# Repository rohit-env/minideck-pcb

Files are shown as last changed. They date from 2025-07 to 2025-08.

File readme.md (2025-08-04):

# Rohit's minideck PCB

so I went off and designed a whole cyberdeck pcb, it’s kinda sick, it's a full-on deck with ports, buttons, blinky stuff, and that clean hacker aesthetic. built it because laptops are boring and carrying around raw PCBs just hits different.the board’s got space for a pi, a couple usb ports, an oled, and some clicky switches. stuff’s laid out in a way that makes sense, but also makes you look like you’re about to jack into the matrix at a coffee shop. the idea is simple cram as much functional coolness as possible onto one board and still make it portable enough to flex at meetups. this whole thing started with a sketch on a sticky note and now it’s a real life project(obviously i need money to make it real). i even left space for expansion headers because future proofing or whatever. no idea how many late nights went into routing this lol



---

# features 

Uses Raspberry-pi CM4 form-factor for main SBC.

5inch or 4.3inch LCD display with support for another External Display out port.

Uses ESP32-S2 for all the secondary functions including keyboard and mouse control.

61 key customizable keyboard, 6 shoulder button for navigation.

3D hall-effect joystick is used for proper Mouse control.

10000mAh(21700) 2S battery can be used for main power source.

USB-PD 2Amps fast charging using USB-C port.

One USB-A and display out for external display.

USB-C formfactor Nurolink/docking port with UART, I2C.

---

| Image | Description |
|---|---|
|  | top |

| Image | Description |
|---|---|
|  | side |

| Image | Description |
|---|---|
|  | top side |

| Image | Description |
|---|---|
|  | main pcb render |

| Image | Description |
|---|---|
|  | display pcb render |

| Image | Description |
|---|---|
|  | main pcb |

| Image | Description |
|---|---|
|   | display pcb |

----

# BOM

| **Component** | **Description** | **Qty** | **Estimated Price (USD)** | **Link** |
|---|---|---|---|---|
| **PCB** | Custom PCB | 1 | $92 (without pcba after $20 coupon) | JLCPCB  |
| **4.3 inch display** | Display for the deck | 1 | $36.16 | [Robocraze](https://robocraze.com/products/waveshare-4-3inch-dsi-lcd-capacitive-touch-display-800-480-for-raspberry-pi) |
| **21700 batteries** | Batteries | 1 (pair) | $10.41 | [Drkstore](https://www.drkstore.in/molicel-inr-21700-p45b-3-6v-4500mah-10c-li-ion-battery/) |
| **5V Voltage Regulator** | Power regulator for the display | 2 | $11.76 | [Robocraze](https://robocraze.com/products/dfrobot-multi-output-dc-dc-buck-converter-module-3-3v-5v-9v-12v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) |
| **ESP32 Microcontroller**| Controls everything in the device (keyboard, mouse, etc.) | 1 | $0 | Already available |
| **Raspberry Pi Compute Module** | Heart of the device | 1 | $80 | [Robu](https://robu.in/product/raspberry-pi-compute-module-5-2gb-32gb/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) |

BOM: $229

# gallery






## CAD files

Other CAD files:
CAD/fusionparts/body_bottom.f3d
CAD/fusionparts/body_top.f3d
CAD/fusionparts/display_bottom.f3d
CAD/fusionparts/display_top.f3d
CAD/fusionparts/mid_frame.f3d

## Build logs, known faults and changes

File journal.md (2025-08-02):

total hours spent: 43 hours.

### July 8, 2025  
**time spent:** 2 hours  

got started with the power stuff today because that felt like a good anchor  
opened up a blank KiCad sheet and just kinda sat there before committing to the first buck converter  
threw in a couple AP62300s, added some random caps that looked about right  
did basic power rails like +3.3VA and +5V, mostly by guessing current draw  
honestly spent more time figuring out resistor values than placing parts  
it's still super rough, but at least the board’s not completely empty anymore  
definitely not thinking about routing yet

| what happened | image |
|---|---|
| got the power rails and buck converters roughly figured out |   |

---

### July 9, 2025  
**time spent:** 1.5 hours  

dove headfirst into HDMI today and instantly regretted it  
the connector footprint was cursed and I had to double-check every diff pair  
wired up the HDMI chip and some tiny filter caps for signal integrity  
had to decide whether to bother with hotplug detection and i just YOLO’d it in  
tried to keep traces as short as possible even though I haven’t routed anything  
also added pull-ups and random ESD protection that I may or may not actually populate  
got through it alive, but just barely

| what happened | image |
|---|---|
| threw in the hdmi stuff, wasn’t sure if i was wiring it right tbh |  |

---

### July 11, 2025  
**time spent:** 2.5 hours  

today was CM4 Lite day, and man this thing has a crazy number of pins  
literally had to scroll through three different PDFs to not mess up the IO mapping  
figured out where to connect PCIe and eMMC signals even though I’m not using either  
started drawing out the main headers and labeling them so I wouldn’t cry later  
threw in level shifters and testpoints just to be safe  

| what happened | image |
|---|---|
| added the cm4 lite footprint and some essentials around it |  |

---

### July 12, 2025  
**time spent:** 1 hour  

today was about the esp32 and the USB hub, two chips I really like but hate wiring  
added the esp32 footprint and spent too long assigning IOs  
for the usb hub, I was constantly bouncing between the datasheet and KiCad  
wired up USB upstream/downstream lines and crossed my fingers on signal integrity  
threw in some debug headers and left room for ESD stuff I haven’t decided on yet  
also started routing logic enable signals to give me more control later  
kinda messy but functionally complete

| what happened | image |
|---|---|
| hooked up the esp and usb hub chip, still unsure about esd protection here | |

---

### July 14, 2025  
**time spent:** 1.5 hours  

this was cleanup day, had to declutter a lot of overlapping nets  
focused on GPIO and voltage domains because things were starting to get scary  
double checked voltage levels everywhere and pulled back any accidental 5V hits  
renamed nets to stuff like USB_D+ and PWR_BTN so I don’t get lost later  
added a few jumpers where I needed config flexibility

| what happened | image |
|---|---|
| the gpio, ethernet, sd signals etc., are getting crowded |
  |

---

### July 16, 2025  
**time spent:** 2 hours  

felt like expanding the UI side today, so buttons and switches got added  
dropped in an IO expander to control all the random toggles I want  
added RGB LED, backlight control, and the mandatory cyberpunk toggle  
also threw in debug pads and labeled everything just in case I forget stuff later  
double checked how the esp talks to the neopixel

| what happened | image |
|---|---|
| added a bunch of buttons, switches, and gpio expands |  |

---

### July 18, 2025  
**time spent:** 1 hour  

focused entirely on the battery and power switch logic today  
added charging ICs, battery monitor, and some MOSFET magic for switching  
realized I forgot to add thermistor protection, so threw that in last minute  
checked current sense resistor values like 5 times because battery fires aren’t cool  
rewired the main power path so everything’s a bit safer  
design is power-heavy now but kinda elegant  
will probably still debug it with a fire extinguisher nearby

| what happened | image |
|---|---|
| threw in the power switch logic and battery protection circuit |
  |

---

### July 20, 2025  
**time spent:** 3 hours  

long session today, mostly organizing the whole schematic properly  
split things into hierarchy sheets because the top level was getting out of control  
reassigned power domains and labeled them to make layout cleaner later  
caught a bunch of dumb mistakes like misnamed nets and flipped diodes  
also started writing notes inside schematic blocks to help future-me  
deleted some sketchy looking wires and redrew for clarity  
design now feels like an actual engineering thing and not a spaghetti nightmare

| what happened | image |
|---|---|
| general cleanup and better power domain separation | 
  |

---

### July 21, 2025  
**time spent:** 2 hours  

this one was about the screen and making sure it won’t fry  
hooked up the LCD interface and added ESD resistors on all the touch lines  
tried to keep traces short even though I’m still in schematic mode  
double checked the display’s backlight, touchscreen, and data lines  
added a debug header just to probe signals later if things don’t work  
organized the connector pins to make layout easier  
this part was clean.

| what happened | image |
|---|---|
| display interface is finally somewhat sane |
   |

---

### July 22, 2025  
**time spent:** 1.5 hours  

wrapped up the final round of cleanup and review today  
triple-checked pinouts, footprints, and power rails for errors  
added fiducials, test points, and random extras like boot jumpers  
also finalized the USB-C and HDMI protection stuff  

---

### July 23, 2025
**time spent:** 4 hours  

worked on deciding the dimensions for the pcb borders and made sure that it fit my case dimensions that i have planned, also many components i placed on the board, just the process of deciding the border length took a lot of time, started routing the pcb and i finished abtu 20% of it, i am thinking of importing it to easy eda pro and autorouting it but i want the source files so ill keep it

---

### july 24,2025 
**time spent:** 3 hours  

today i finished routing the display pcb, and started routing the main pcb, it did take a lot of retries since i had to replace parts and i finally found a suitable arrangement, routig all the parts in the main pcb was pretty hectic, ive finished like 70% of it, i've got school stuff to do now so imma take the night off

---

### July 26, 2025
**time spent:** 2 hours 

started work on the display PCB today and honestly this one's way calmer than the main board  
got the basic stuff in first power input, the FPC connector for the screen, and some random passives  
had to rotate the layout like 3 times to make the FPC orientation make sense  
added pull-up resistors.

| what happened | image |
|---|---|
| finished the display PCB design, it’s looking clean and minimal |  |

---

### July 28, 2025  
**time spent:** 3 hours  

big day finished up the main PCB layout and it’s giving boss battle energy  
revisited every sheet and double checked for footprint mismatches or missing caps  
replaced some jank passives from earlier with proper parts and cleaned up nets  
went full sent on layout had to rip up the power plane.

| what happened | image |
|---|---|
| final layout of the main PCB, all the chaos finally connected |  |

---

### july 29,2025
**time spent:** 3 hours  

finished doing the firmware, got nothing to say about this one.

---

### July 29, 2025 ( in the night ) 
**time spent:** 2 hours  
Did more work on the case for the display PCB today. Most of the time went into figuring out the outer dimensions so the board actually fits in clean. Kept adjusting a few mm here and there to match the rough size I had in my head. Took way longer than it should’ve. Once that was sorted, I started adding the cutouts and screw holes. made sure the ports had breathing room, and triple-checked all the hole spacing. Don’t wanna be that guy who forgets to leave space for the USB port. Didn’t bother adding fillets or rounded corners yet just getting the basic shape right for now. Might tweak the aesthetics later once I test fit the first cut. But yeah, it’s finally starting to look like a proper case.
| what happened | image |
|---|---|
| sneak peaks |  |
| sneak peaks |  |

---

### July 30, 2025( early morning )
**time spent** 4 hours
Started designing the bottom half of the display case today. The goal was to keep it simple but still make sure everything lines up clean. Took a bit of time messing with dimensions—mainly double checking hole positions it matched the PCB layout. Rounded off the corners to make it less boxy and added a small notch for cable clearance later if I need it. The cutouts for the screen area and the mounts came out nice in the 3D preview.

Honestly just getting the case to sit right with the PCB was half the battle, but it looks solid now. Ready to move on to the top half next.
| what happened | image |
|---|---|
| sneak peaks |  |
| sneak peaks |  |

---

### July 30, 2025( night)
**time spent** 2 hours

I started working on the top half of the case. This part was kind of annoying, to be honest. I had to figure out the exact cutout for the display and ensure it sat flush without pressing too hard on the screen. It took a few tries to get the depth right. I kept toggling between the model and the actual display dimensions just to be sure.Then came the USB port clearance, which was a real hassle. Tiny shifts made it either not fit or too loose. I finally added a small beveled area around it so it wouldn’t scrape while plugging things in. I also had to make sure the mounting holes lined up perfectly with the bottom half. I used offsets and several measuring tools in Fusion to get it right. I added a little lip around the edges to help with alignment when snapping it on, and I created some space inside for routing wires from the display. It’s not the prettiest lid, but it gets the job done. I might refine the outer surface later to make it look cleaner. For now, I’m just focused on function.
| what happened | image |
|---|---|
| sneak peaks |  |
| sneak peaks |  |

---

### July 31,2025
**time spent** 2 hours

spent most of the evening just modeling the top half of the display case. it honestly took longer than expected lining everything up with the pcb was kind of a pain. had to double check the display cutout, standoff placement, and make sure nothing would crash into the components later. i played around with the screen window quite a bit… didn’t want it to look bulky, but also didn’t want it too snug and risk it scraping the screen when assembled. added a few guiding walls inside so the pcb can sort of “slot in” when it’s time. should help with alignment too. tweaked tolerances here and there, especially around the screen opening. might still need adjustments after the first print, but visually it’s looking nice.
not the most fun part of the build, but we’re getting there.

| what happened | image |
|---|---|
| sneak peaks | 
 |
| sneak peaks |   |

---

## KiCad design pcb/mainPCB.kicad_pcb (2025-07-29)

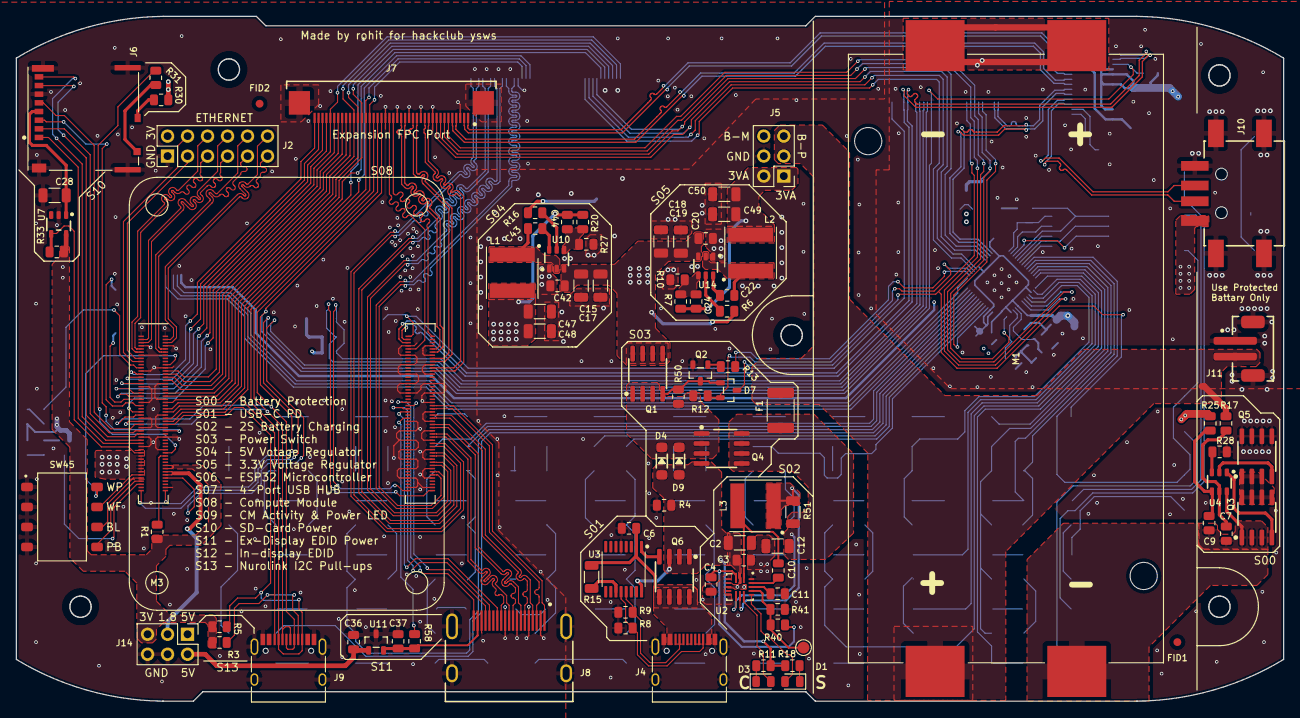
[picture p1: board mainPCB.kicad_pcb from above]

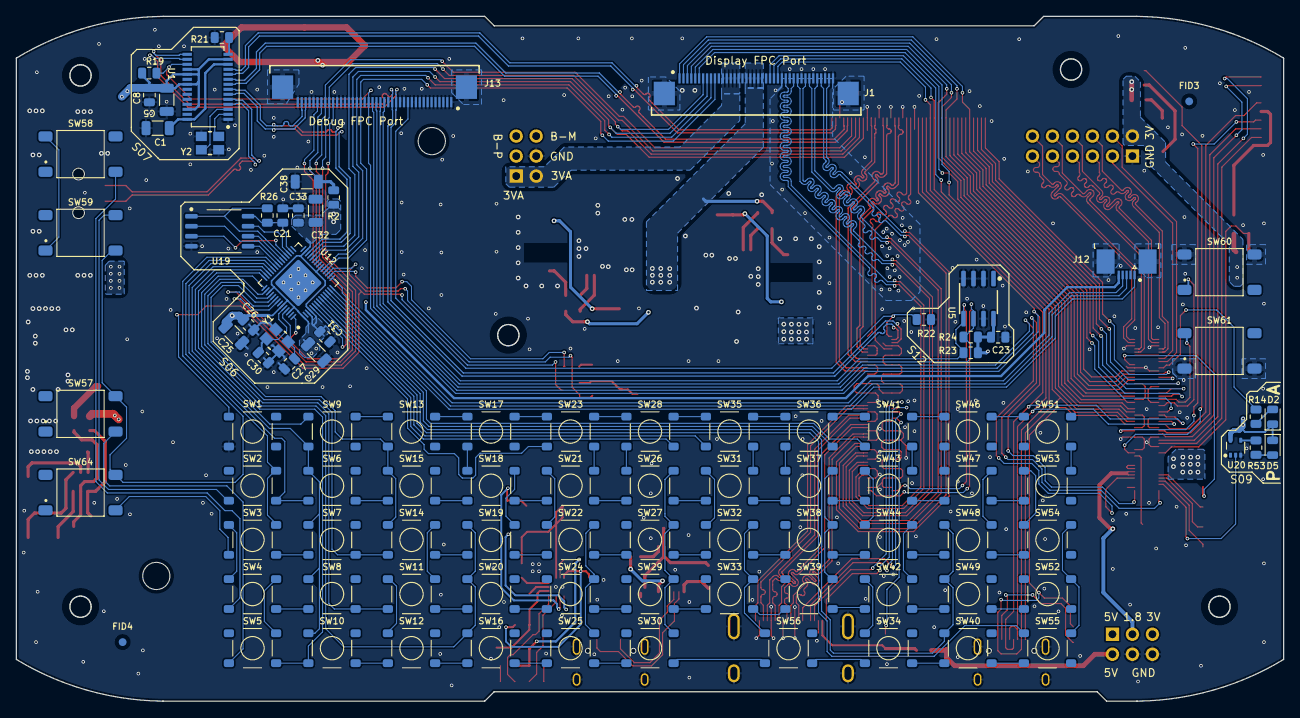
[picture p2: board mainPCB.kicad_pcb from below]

Board: 4 copper layers, 161.0 x 87.0 mm, 194 parts (97 on the bottom side), 260 nets.

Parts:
C1, C5, C15, C17, C18, C19, C25, C28, C29, C32, C38: 10uF; Capacitor-1206
C2, C12, C47, C48, C49, C50: 22uF; Capacitor-1206
C3, C4, C6, C11: 1uF; Capacitor-0805
C7, C8, C9, C10, C20, C21, C22, C23, C26, C31, C33, C36, C37, C42, C43: 0.1uF; Capacitor-0805
C24, C44: 100pF; Capacitor-0805
C27, C30: 16pF; Capacitor-0805
D1, D2, D3, D5: LED; LED-0805
D4, D9: MBR0540T3G; Diode-SOD-123
D7: BAT54C-(SOT23); SOT-23-3
F1: 0ZCG0260BF2B; Fuse-1812
FID1, FID2, FID3, FID4: Fiducial; Fiducial_1mm_Mask2mm
H1, H2, H3, H4, H5: MountingHole_Pad; MountingHole-M2.5-D2.7mm
J1, J7, J13: CF20401D0R0-NH; FPC-40-0.5mm-horizontal
J2: Conn_02x06-(RS2-12-G); PinHeader_2x06_P2.54mm_Vertical
J4, J9: 12402012E212A; USB_C-Female-(16-Pin)
J5, J14: Conn_02x03-(RS2-06-G); PinHeader_2x03_P2.54mm_Vertical
J6: Micro_SD_Card_Det; SD-Micro-Push-Push(MOLEX_503398-1892)
J8: HDMI_A-(2086581051); HDMI(EDAC 690-019-298-412)
J10: 629104190121; USB_A-horizontal-SMD-3
J11: B2B-PH-SM4-TB; JST-PH2-Vertical
J12: SFV5R-2STBE1HLF; FPC-5-0.5mm-horizontal
L1, L2: 10uH-(74404064100); Inductor-6.0x6.0xH4.5
L3: 6.8uH-(74404064068); Inductor-6.0x6.0xH4.5
M1: keystone-PN1048; Battery_holder-18650x2(keystone-PN1048)
M3: DF40C-100DS-0.4V(51); Module-ComputeModule4-CM4
Q1, Q4: DMP3037LSS-13; SOP-8
Q2: BCW66HVL-(2N2222); SOT-23-3
Q3, Q5: MOSFET-N; SOP-8
Q6: AOSP36326C; SOP-8
R1, R22, R28: 2.2k; Resistor-0805
R2, R3, R4, R5, R10, R12, R27, R40, R41, R50, R58: 10k; Resistor-0805
R6, R16, R19, R23, R24, R26, R33: 100k; Resistor-0805
R7: 33.2K; Resistor-0805
R8, R9: 5.1k; Resistor-0805
R11, R14, R18, R53: 1k; Resistor-0805
R13, R30, R31: 220R; Resistor-0805
R15: 5.1k; Resistor-1206
R17, R25: 330R; Resistor-0805
R20: 56.2k; Resistor-0805
R21: 2.7k; Resistor-0805
R51: 50mR; Resistor-1206
SW1, SW2, SW3, SW4, SW5, SW6, SW7, SW8, SW9, SW10, SW11, SW12, SW13, SW14, SW15, SW16, SW17, SW18, SW19, SW20, SW21, SW22, SW23, SW24, SW25, SW26, SW27, SW28, SW29, SW30, SW31, SW32, SW33, SW34, SW35, SW36, SW37, SW38, SW39, SW40, SW41, SW42, SW43, SW44, SW46, SW47, SW48, SW49, SW51, SW52, SW53, SW54, SW55, SW56: PTS526 SK15 SMTR2 LFS-(C&K); Switch-4x4x1.5-(PTS526)
SW45: Switch-6.2X4-DIP(DS04-254-2-04BK)
SW57, SW58, SW59, SW60, SW61, SW64: TS04-66-85-BK-160-SMT; Switch-6x6xXX-Extend
TP16: THERM; TestPoint-Pad_D1.5mm
U1: FE1.1S-BSOP28BCN; SSOP-28 (3.9x9.9x0.635)
U2: MP2615CGQ-Z-(QFN-16); QFN-16 (3x3-MP2615)
U3: IP2721-(TSSOP-16); TSSOP-16
U4: MM3220/S8252-(SOT-23-6); SOT-23-6
U5: AT24CM01-SSHM-B; SOP-8
U7: RT9742GGJ5; SOT-23-5
U10, U14: AP62300TWU-7-(SOT-23-6); SOT-23-6
U11: RT9742SNGV; SOT-23-3
U12: ESP32-S2FH4; QFN-56 (7x7x0.4)
U19: W25Q128JVS; SOIC-8-208mil
U20: 74LVC1G07SE-7-(SOT-353); SOT-353
Y1: 40mhz-(RH100-40.000-16-F-1010-TR); Crystal-3225-SMD
Y2: 12MHz-(RH100-12.000-12-1010-X-TR-NS2); Crystal-3225-SMD

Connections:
1: SW2.4, SW3.4, U12.38 (GPIO34)
1D+: J10.3 (D+), U1.5 (DP4)
1D-: J10.2 (D-), U1.4 (DM4)
2: SW6.3, SW7.3, SW8.3, SW9.1, SW10.3, U12.40 (GPIO36)
2D+: J13.39, U1.7 (DP3), U12.26 (GPIO20/USB_P)
2D-: J13.38, U1.6 (DM3), U12.25 (GPIO19/USB_N)
3: SW13.1, SW14.3, SW15.3, U12.47 (GPIO42)
3D+: J7.4, U1.9 (DP2)
3D-: J7.5, U1.8 (DM2)
4: SW16.3, SW19.3, SW20.3, U12.43 (GPIO39)
4D+: J7.1, U1.11 (DP1)
4D-: J7.2, U1.10 (DM1)
5: SW23.1, U12.6 (GPIO1)
6: SW28.2, U12.7 (GPIO2)
7: SW35.1, U12.8 (GPIO3)
8: SW36.2, U12.11 (GPIO6)
9: SW41.1, U12.12 (GPIO7)
10: SW40.3, SW48.3, SW49.3, U12.10 (GPIO5)
11: SW55.3, U12.9 (GPIO4)
12: SW57.4, SW59.2, SW64.4, U12.37 (GPIO33)
+3.3V: D2.A, D5.A, J2.2, J14.5, M3.84 (+3.3v_(Output)), M3.86 (+3.3v_(Output)), R1.1, R3.1, R5.1, R30.1, R33.1, U7.5 (IN), U20.5 (VCC)
+3.3VA: C5.1, C8.1, C24.2, C25.2, C26.2, C29.2, C31.2, C32.2, C33.2, C49.2, C50.2, J1.12, J1.13, J1.14, J1.15, J1.16, J5.1, J5.2, J12.5, L2.2, R2.2, R7.1, R19.2, U1.13 (VD33), U1.18 (VBUSM), U1.19 (BUSJ), U1.21 (VD33_O), U1.26 (OVCJ), U12.1 (VDDA), U12.3 (VDD3P3), U12.4 (VDD3P3), U12.20 (VDD3P3_RTC), U12.27 (VDD3P3_RTC_IO), U12.45 (VDD3P3_CPU), U12.51 (VDDA), U12.54 (VDDA)
+5V: C23.2, C36.1, C44.2, C47.2, C48.2, J10.1 (VBUS), J14.1, J14.2, L1.2, M3.77 (+5v_(Input)), M3.79 (+5v_(Input)), M3.81 (+5v_(Input)), M3.83 (+5v_(Input)), M3.85 (+5v_(Input)), M3.87 (+5v_(Input)), R20.1, R23.2, R24.2, U5.8 (VCC), U11.1 (IN)
+12V: C2.2, C3.2, D4.A, D9.A, Q4.4, Q6.1, Q6.2, Q6.3, R4.1, R11.2, R18.2, U2.2 (VIN), U3.16 (VBUS)
+BATT: F1.2, J5.3, J5.5, J11.2, M1.1, R17.1
+VDC: C12.2, F1.1, Q4.5, Q4.6, Q4.7, Q4.8, R51.1, U2.9 (BATT)
-BATT: C7.1, C9.1, M1.3, Q3.1, Q3.2, Q3.3, U4.6 (GND)
/+1.8v: J14.3, M3.88 (+1.8v_(Output)), M3.90 (+1.8v_(Output))
/ACOK: D1.C, U2.12 (*ACOK)
/Activity_LED: M3.21 (PI_nLED_Activity), R14.2
/BT_nDis: M3.91 (BT_nDisable), SW45.3B
/Charger_SW_Out: L3.1, R51.2, U2.10 (CSP)
/EEPROM_nWP: M3.20 (EEPROM_nWP), SW45.1B
/ETH_0_N: J2.9, M3.10 (Ethernet_Pair0_N)
/ETH_0_P: J2.10, M3.12 (Ethernet_Pair0_P)
/ETH_1_N: J2.11, M3.6 (Ethernet_Pair1_N)
/ETH_1_P: J2.12, M3.4 (Ethernet_Pair1_P)
/ETH_2_N: J2.5, M3.9 (Ethernet_Pair2_N)
/ETH_2_P: J2.6, M3.11 (Ethernet_Pair2_P)
/ETH_3_N: J2.7, M3.5 (Ethernet_Pair3_N)
/ETH_3_P: J2.8, M3.3 (Ethernet_Pair3_P)
/ETH_LEDG: J2.4, M3.17 (Ethernet_nLED2(3.3v))
/ETH_LEDY: J2.3, M3.15 (Ethernet_nLED3(3.3v))
/GLOBAL_EN: J13.21, M3.99 (Global_EN)
/GPIO2: J1.26, J7.26, J9.A5 (CC1), J9.B5 (CC2), M3.58 (GPIO2), R5.2
/GPIO3: J1.25, J7.27, J9.A8 (SBU1), J9.B8 (SBU2), M3.56 (GPIO3), R3.2
/GPIO4: J1.24, M3.54 (GPIO4)
/GPIO6: J7.31, M3.30 (GPIO6)
/GPIO7: J7.37, M3.37 (GPIO7)
/GPIO8: J1.1, J7.36, M3.39 (GPIO8)
/GPIO9: J1.3, J7.29, M3.40 (GPIO9)
/GPIO10: J1.4, J7.28, M3.44 (GPIO10)
/GPIO11: J1.2, J7.30, M3.38 (GPIO11)
/GPIO12: J7.38, M3.31 (GPIO12)
/GPIO13: J7.32, M3.28 (GPIO13)
/GPIO14: J7.25, J9.A7 (D-), J9.B7 (D-), M3.55 (GPIO14)
/GPIO15: J7.24, J9.A6 (D+), J9.B6 (D+), M3.51 (GPIO15)
/GPIO17: J1.5, M3.50 (GPIO17)
/GPIO18: J7.35, M3.49 (GPIO18)
/GPIO19: J7.33, M3.26 (GPIO19)
/GPIO20: J7.39, M3.27 (GPIO20)
/GPIO21: J7.40, M3.25 (GPIO21)
/GPIO24: M3.45 (GPIO24), SW60.1
/GPIO25: M3.41 (GPIO25), SW61.3
/GPIO26: J7.34, M3.24 (GPIO26)
/GPIO27: J1.6, M3.48 (GPIO27)
/GPIO_VREF: M3.78 (GPIO_VREF(1.8v/3.3v_Input)), R1.2
/HDMI0_CK_N: J1.28, M3.190 (HDMI0_CLK_N)
/HDMI0_CK_P: J1.30, M3.188 (HDMI0_CLK_P)
/HDMI0_D0_N: J1.31, M3.184 (HDMI0_TX0_N)
/HDMI0_D0_P: J1.33, M3.182 (HDMI0_TX0_P)
/HDMI0_D1_N: J1.34, M3.178 (HDMI0_TX1_N)
/HDMI0_D1_P: J1.36, M3.176 (HDMI0_TX1_P)
/HDMI0_D2_N: J1.37, M3.172 (HDMI0_TX2_N)
/HDMI0_D2_P: J1.39, M3.170 (HDMI0_TX2_P)
/HDMI0_HOTPLUG: M3.153 (HDMI0_HOTPLUG), R58.2
/HDMI0_SCL: J13.19, M3.200 (HDMI0_SCL), R24.1, U5.6 (SCL)
/HDMI0_SDA: J13.18, M3.199 (HDMI0_SDA), R23.1, U5.5 (SDA)
/HDMI1_CEC: J8.13 (CEC), M3.149 (HDMI1_CEC)
/HDMI1_CK_N: J8.12 (CK-), M3.166 (HDMI1_CLK_N)
/HDMI1_CK_P: J8.10 (CK+), M3.164 (HDMI1_CLK_P)
/HDMI1_D0_N: J8.9 (D0-), M3.160 (HDMI1_TX0_N)
/HDMI1_D0_P: J8.7 (D0+), M3.158 (HDMI1_TX0_P)
/HDMI1_D1_N: J8.6 (D1-), M3.154 (HDMI1_TX1_N)
/HDMI1_D1_P: J8.4 (D1+), M3.152 (HDMI1_TX1_P)
/HDMI1_D2_N: J8.3 (D2-), M3.148 (HDMI1_TX2_N)
/HDMI1_D2_P: J8.1 (D2+), M3.146 (HDMI1_TX2_P)
/HDMI1_HOTPLUG: J8.19 (HPD/HEAC-), M3.143 (HDMI1_HOTPLUG)
/HDMI1_SCL: J8.15 (SCL), M3.147 (HDMI1_SCL)
/HDMI1_SDA: J8.16 (SDA), M3.145 (HDMI1_SDA)
/HDMI_5v: C37.1, J8.18 (+5V), R58.1, U11.2 (OUT)
/PCIE_CLK_N: J7.17, M3.112 (PCIe_CLK_N)
/PCIE_CLK_P: J7.18, M3.110 (PCIe_CLK_P)
/PCIE_CLK_nREQ: J7.20, M3.102 (PCIe_CLK_nREQ)
/PCIE_RX_N: J7.14, M3.118 (PCIe_RX_N)
/PCIE_RX_P: J7.15, M3.116 (PCIe_RX_P)
/PCIE_TX_N: J7.11, M3.124 (PCIe_TX_N)
/PCIE_TX_P: J7.12, M3.122 (PCIe_TX_P)
/PCIE_nRST: J7.21, M3.109 (PCIe_nRST)
/PWR_LED: M3.95 (nPI_LED_PWR), U20.2
/RUN_PG: J13.20, M3.92 (RUN_PG)
/Reserved: M3.76 (Reserved), R31.1
/SD_CLK: J6.5 (CLK), M3.57 (SD_CLK)
/SD_CMD: J6.3 (CMD), M3.62 (SD_CMD)
/SD_DAT0: J6.7 (DAT0), M3.63 (SD_DAT0)
/SD_DAT1: J6.8 (DAT1), M3.67 (SD_DAT1)
/SD_DAT2: J6.1 (DAT2), M3.69 (SD_DAT2)
/SD_DAT3: J6.2 (DAT3/CD), M3.61 (SD_DAT3)
/SD_PWR: C28.2, J6.4 (VDD), U7.1 (OUT)
/SD_PWR_ON: M3.75 (SD_PWR_ON), R33.2, U7.4 (EN)
/USB2_N: J13.16, M3.103 (USB2_N), U1.15 (DMU)
/USB2_P: J13.15, M3.105 (USB2_P), U1.16 (DPU)
/USBOTG_ID: J13.12, M3.101 (USB_OTG_ID), R22.2
/WL_nDis: M3.89 (WiFi_nDisable), SW45.2B
/fb_3.3: C24.1, R7.2, R10.1, U14.4 (FB)
/fb_5: C44.1, R20.2, R27.1, U10.4 (FB)
/nEXTRST: J7.23, J13.22, M3.100 (nEXTRST), R19.1, U1.17 (~XRSTJ)
/nRPIBOOT: M3.93 (nRPIBOOT), SW45.4B
/sw3.3v: C22.2, L2.1, U14.2 (SW)
/sw5v: C43.2, L1.1, U10.2 (SW)
A: SW9.3, U12.41 (GPIO37)
B: SW2.2, SW6.1, U12.39 (GPIO35)
BAT_mid: J5.6, M1.2, M1.4, R25.1
BOOT0: J13.35, U12.5 (GPIO0)
BRIGTNESS_LCD: J1.10, J13.24, U12.18 (GPIO13)
BUT: J12.3, U12.14 (GPIO9)
C: SW7.2, SW14.1, U12.46 (GPIO41)
CC1: J4.A5 (CC1), R9.1, U3.13 (CC1)
CC2: J4.B5 (CC2), R8.1, U3.12 (CC2)
D: SW8.2, SW11.1, U12.44 (GPIO40)
E: SW5.2, SW10.1, U12.42 (GPIO38)
GND: C1.2, C2.1, C3.1, C4.1, C5.2, C6.1, C8.2, C11.1, C12.1, C15.1, C17.1, C18.1, C19.1, C20.2, C21.2, C23.1, C25.1, C26.1, C27.1, C28.1, C29.1, C30.1, C31.1, C32.1, C33.1, C36.2, C37.2, C38.1, C42.2, C47.1, C48.1, C49.1, C50.1, J1.27, J1.29, J1.32, J1.35, J1.38, J1.40, J1.Z1, J1.Z2, J2.1, J4.GND, J4.S, J5.4, J6.6 (VSS), J6.11 (SHIELD), J7.3, J7.10, J7.13, J7.16, J7.19, J7.22, J7.Z1, J7.Z2, J8.2 (D2S), J8.5 (D1S), J8.8 (D0S), J8.11 (CKS), J8.17 (GND), J8.SH1 (SH), J8.SH2 (SH), J8.SH3 (SH), J8.SH4 (SH), J9.GND, J9.S, J10.4 (GND), J10.S (SHIELD), J11.1, J11.Z1, J11.Z2, J12.2, J12.Z1, J12.Z2, J13.1, J13.2, J13.3, J13.4, J13.5, J13.6, J13.7, J13.8, J13.9, J13.10, J13.11, J13.13, J13.14, J13.17, J13.23, J13.28, J13.29, J13.30, J13.36, J13.37, J13.40, J13.Z1, J13.Z2, J14.4, J14.6, M3.1 (GND), M3.2 (GND), M3.7 (GND), M3.8 (GND), M3.13 (GND), M3.14 (GND), M3.22 (GND), M3.23 (GND), M3.32 (GND), M3.33 (GND), M3.42 (GND), M3.43 (GND), M3.52 (GND), M3.53 (GND), M3.59 (GND), M3.60 (GND), M3.65 (GND), M3.66 (GND), M3.71 (GND), M3.74 (GND), M3.98 (GND), M3.107 (GND), M3.108 (GND), M3.113 (GND), M3.114 (GND), M3.119 (GND), M3.120 (GND), M3.125 (GND), M3.126 (GND), M3.131 (GND), M3.132 (GND), M3.137 (GND), M3.138 (GND), M3.144 (GND), M3.150 (GND), M3.155 (GND), M3.156 (GND), M3.161 (GND), M3.162 (GND), M3.167 (GND), M3.168 (GND), M3.173 (GND), M3.174 (GND), M3.179 (GND), M3.180 (GND), M3.185 (GND), M3.186 (GND), M3.191 (GND), M3.192 (GND), M3.197 (GND), M3.198 (GND), Q2.2 (E), Q5.5, Q5.6, Q5.7, Q5.8, R4.2, R8.2, R9.2, R10.2, R21.1, R22.1, R27.2, R28.2, R41.2, SW1.1, SW45.1A, SW45.2A, SW45.3A, SW45.4A, SW60.3, SW60.4, SW61.1, SW61.2, U1.1 (VSS), U2.4 (CELL), U2.5 (SEL), U2.6 (*EN), U2.8 (AGND), U2.16 (PGND), U3.5 (GND), U5.2 (A1), U5.3 (A2), U5.4 (GND), U5.7 (WP), U7.2 (GND), U10.1 (GND), U11.3 (GND), U12.57 (GND), U14.1 (GND), U19.4 (GND), U20.3 (GND), Y1.2, Y1.4, Y2.2, Y2.4
HA: J12.1, U12.13 (GPIO8)
LDR: J1.9, J13.25, U12.19 (GPIO14)
unnamed: D1.A, R18.1
unnamed: D2.C, R14.1
unnamed: D3.A, R11.1
unnamed: D5.C, R53.1
unnamed: D7.1 (A1), Q1.4, Q2.3 (C), R50.1
unnamed: J6.10 (DET_A), R30.2
unnamed: J6.9 (DET_B), R31.2
unnamed: Q2.1 (B), R13.1
unnamed: Q3.5, Q3.6, Q3.7, Q3.8, Q5.1, Q5.2, Q5.3
unnamed: R53.2, U20.4
unnamed: SW2.1, SW59.4
unnamed: SW3.1, SW64.2
unnamed: SW3.2, SW7.1
unnamed: SW3.3, SW4.3
unnamed: SW4.1, SW58.2
unnamed: SW4.2, SW8.1
unnamed: SW4.4, SW5.4
unnamed: SW5.1, SW57.2
unnamed: SW10.2, SW12.1
unnamed: SW11.2, SW20.1
unnamed: SW11.3, SW12.3
unnamed: SW11.4, SW14.4
unnamed: SW12.2, SW16.1
unnamed: SW9.4, SW13.3
unnamed: SW13.4, SW17.3
unnamed: SW14.2, SW19.1
unnamed: SW6.2, SW15.1
unnamed: SW15.2, SW18.1
unnamed: SW16.2, SW25.1
unnamed: SW17.1, SW18.3
unnamed: SW17.4, SW23.3
unnamed: SW18.2, SW21.1
unnamed: SW18.4, SW19.4
unnamed: SW19.2, SW22.1
unnamed: SW20.2, SW24.1
unnamed: SW21.2, SW26.1
unnamed: SW21.3, SW22.3
unnamed: SW21.4, SW23.2
unnamed: SW22.2, SW27.1
unnamed: SW22.4, SW24.4, SW25.4
unnamed: SW23.4, SW28.3
unnamed: SW24.2, SW29.1
unnamed: SW25.2, SW30.1
unnamed: SW26.2, SW31.1
unnamed: SW26.3, SW28.1
unnamed: SW26.4, SW27.4, SW29.4, SW30.4
unnamed: SW27.2, SW32.1
unnamed: SW28.4, SW35.3
unnamed: SW29.2, SW33.1
unnamed: SW30.2, SW56.1
unnamed: SW31.2, SW37.1
unnamed: SW31.3, SW32.3
unnamed: SW31.4, SW35.2
unnamed: SW32.2, SW38.1
unnamed: SW32.4, SW33.4, SW56.3
unnamed: SW33.2, SW39.1
unnamed: SW34.1, SW56.2
unnamed: SW34.2, SW40.1
unnamed: SW34.3, SW42.3
unnamed: SW35.4, SW36.3
unnamed: SW36.1, SW37.3
unnamed: SW36.4, SW41.3
unnamed: SW37.2, SW43.1
unnamed: SW37.4, SW38.4, SW39.4
unnamed: SW38.2, SW44.1
unnamed: SW39.2, SW42.1
unnamed: SW40.2, SW55.1
unnamed: SW41.2, SW43.4
unnamed: SW41.4, SW46.3
unnamed: SW42.2, SW49.1
unnamed: SW42.4, SW44.4
unnamed: SW43.2, SW47.1
unnamed: SW43.3, SW44.3
unnamed: SW44.2, SW48.1
unnamed: SW46.1, SW47.3
unnamed: SW46.4, SW51.3
unnamed: SW47.2, SW53.1
unnamed: SW47.4, SW48.4
unnamed: SW48.2, SW54.1
unnamed: SW49.2, SW52.1
unnamed: SW51.2, SW53.4
unnamed: SW52.4, SW54.4, SW55.4
unnamed: SW53.3, SW54.3
unnamed: SW58.3, SW59.1
unnamed: R21.2, U1.14 (REXT)
unnamed: C1.1, U1.12 (VD18_O), U1.28 (VD18)
unnamed: U1.3 (XIN), Y2.3
unnamed: U1.2 (XOUT), Y2.1
unnamed: D3.C, U2.11 (*CHGOK)
unnamed: C10.1, U2.15 (BST)
unnamed: C10.2, L3.2, U2.1 (SW)
unnamed: C11.2, U2.14 (TMR)
unnamed: C4.2, R40.1, U2.3 (VCC)
unnamed: R15.2, U3.11 (SEL)
unnamed: Q5.4, U4.2 (COUT)
unnamed: Q3.4, U4.1 (DOUT)
unnamed: R28.1, U4.3 (V-)
unnamed: C9.2, R25.2, U4.4 (VBL)
unnamed: C7.2, R17.2, U4.5 (VDD)
unnamed: C43.1, U10.6 (BOOT)
unnamed: R16.2, U10.5 (EN)
unnamed: C22.1, U14.6 (BOOT)
unnamed: R6.2, U14.5 (EN)
POWER: D4.C, D9.C, Q1.1, Q1.2, Q1.3, Q4.1, Q4.2, Q4.3, R12.1, R50.2
POWER_BUTTON: D7.3 (CC), J13.31, SW1.3
POWER_BUTTON_DETECT: D7.2 (A2), R12.2, U12.17 (GPIO12)
POWER_MAIN: R13.2, U12.16 (GPIO11)
Power_Out: C15.2, C17.2, C18.2, C19.2, C20.1, C42.1, J1.18, J1.19, J1.20, J1.21, J1.22, Q1.5, Q1.6, Q1.7, Q1.8, R6.1, R16.1, U10.3 (VIN), U14.3 (VIN)
RX-ESP: J7.7, J13.32, U12.49 (U0RXD)
SCL-ESP: J1.8, J7.9, J13.26, U12.23 (GPIO17/DAC_1)
SDA-ESP: J1.7, J7.8, J13.27, U12.24 (GPIO18/DAC_2)
SPICLK: U12.34 (SPICLK), U19.6 (CLK)
SPICS0: R26.2, U12.33 (SPICS0), U19.1 (~CS)
SPID: U12.36 (SPID), U19.5 (DI(IO0))
SPIHD: U12.31 (SPIHD), U19.7 (IO3)
SPIQ: U12.35 (SPIQ), U19.2 (DO(IO1))
SPIWP: U12.32 (SPIWP), U19.3 (IO2)
TX-ESP: J7.6, J13.33, U12.48 (U0TXD)
Thermistor 2: R40.2, R41.1, TP16.1, U2.13 (NTC)
VA: J12.4, U12.15 (GPIO10)
VBUS: C6.2, J4.VBUS, Q6.5, Q6.6, Q6.7, Q6.8, R15.1, U3.2 (VIN)
VBUS_EN: Q6.4, U3.1 (VBUSG)
VDD_SPI: C21.1, R26.1, U12.30 (VDD_SPI), U19.8 (VCC)
XTAL_N: C30.2, U12.52 (XTAL_N), Y1.3
XTAL_P: C27.2, U12.53 (KTAL_P), Y1.1
~RESET: C38.2, J13.34, R2.1, U12.56 (CHIP_PU)

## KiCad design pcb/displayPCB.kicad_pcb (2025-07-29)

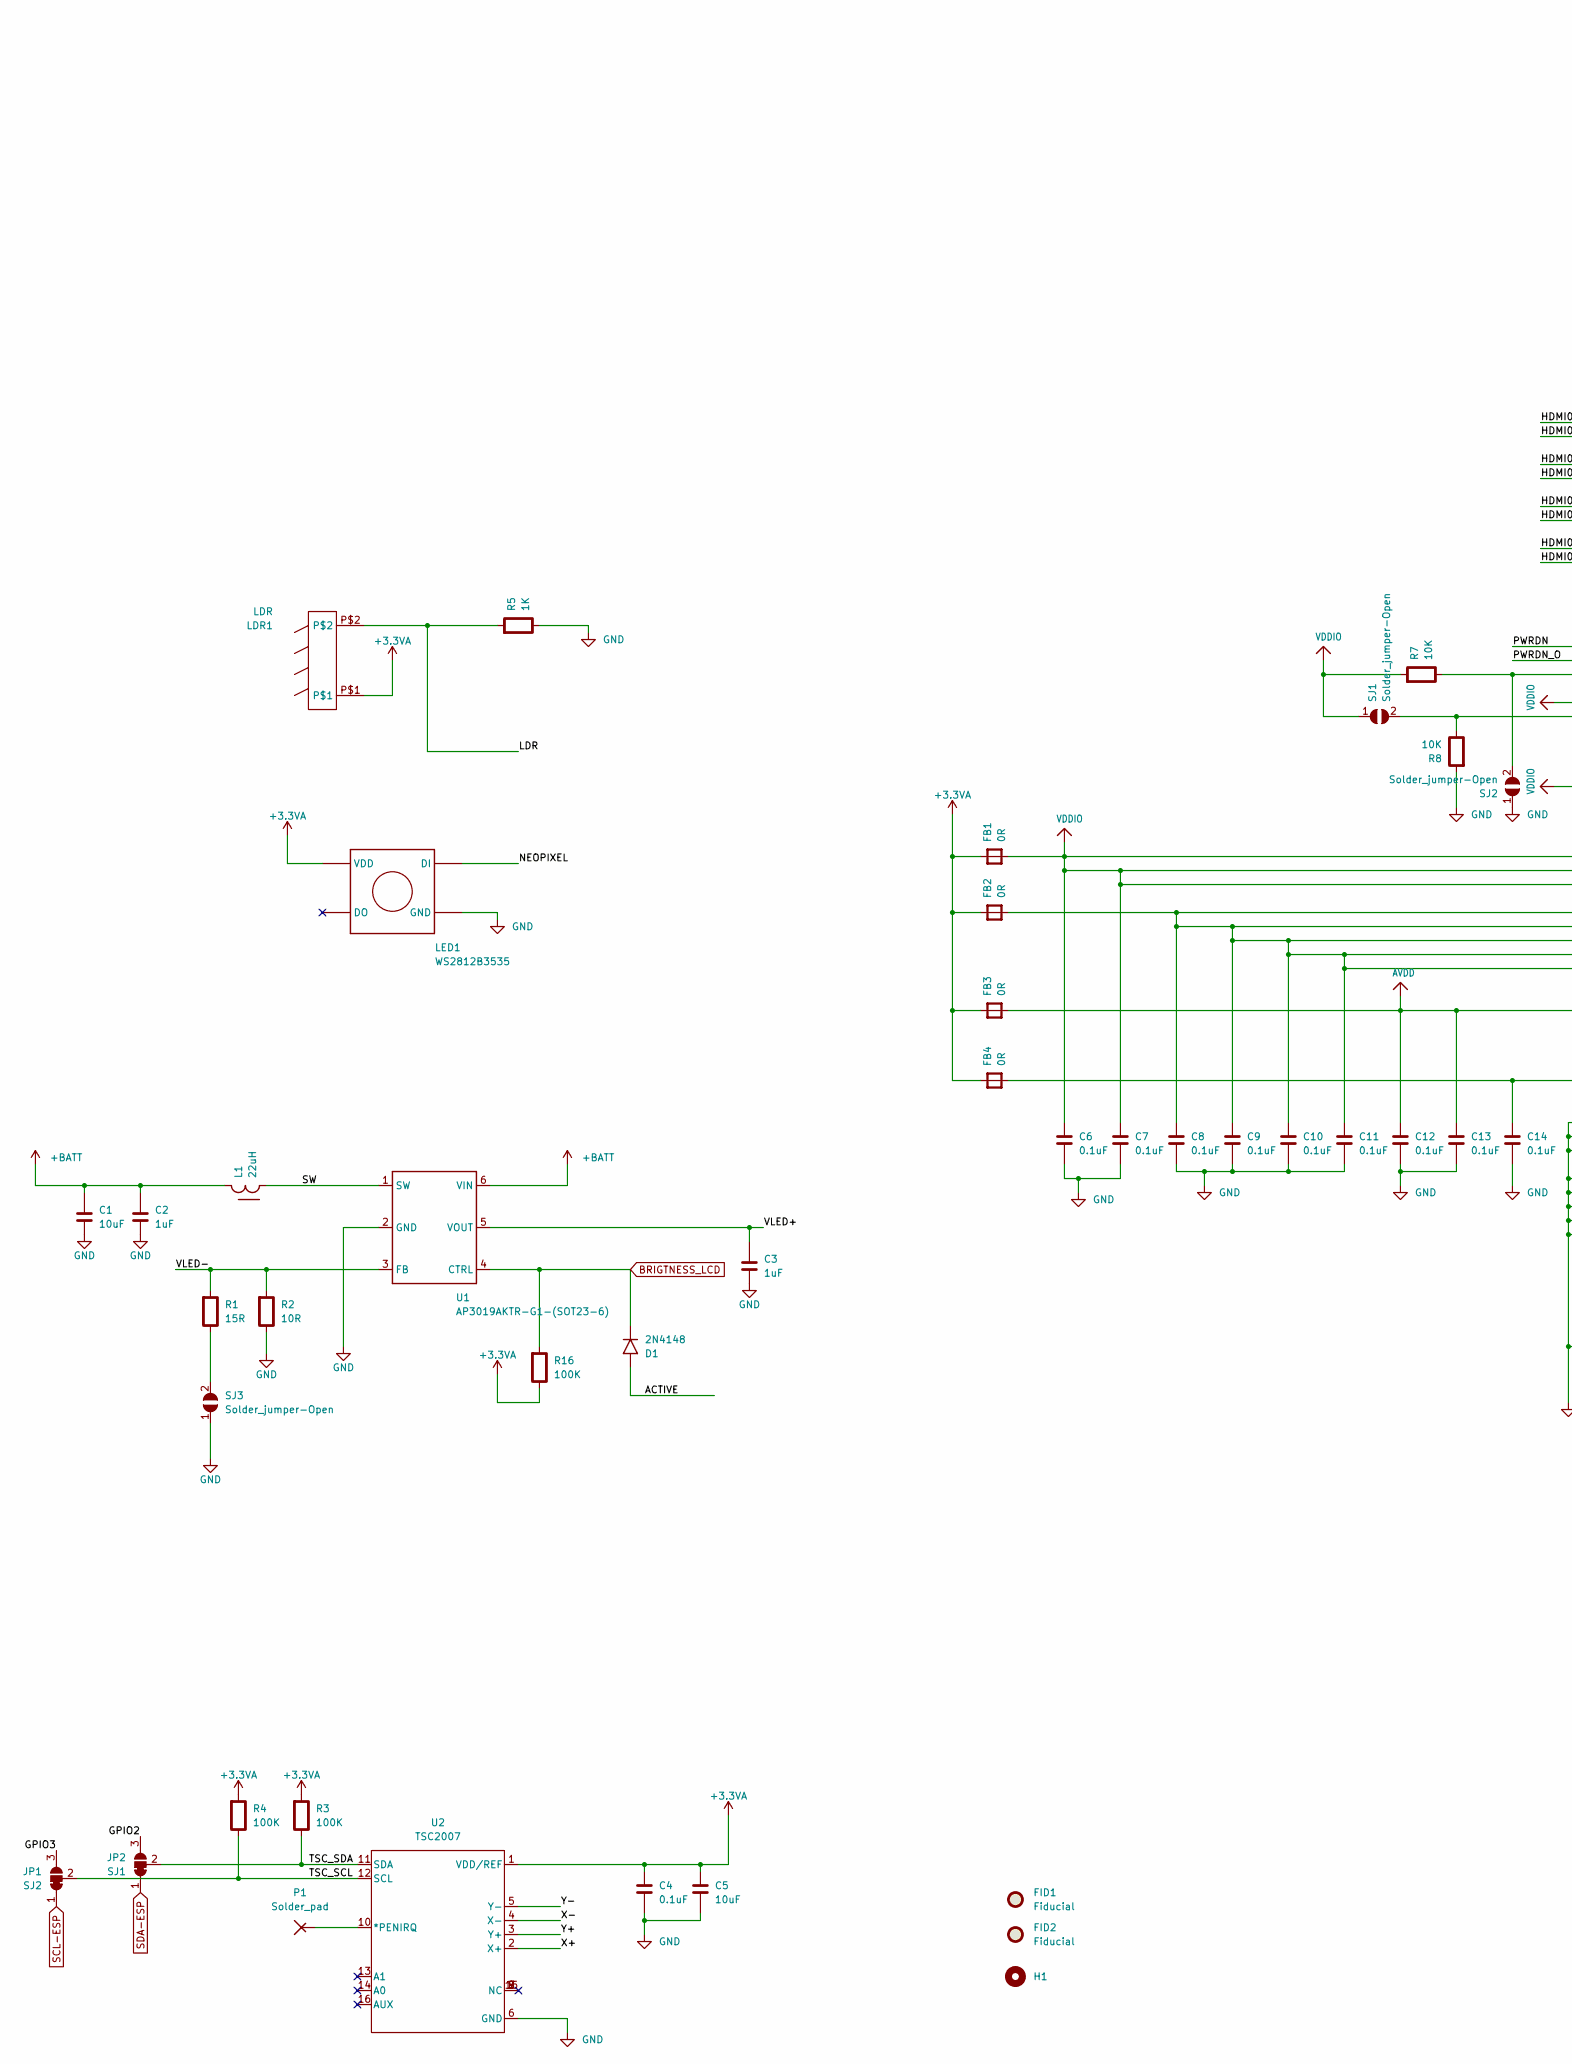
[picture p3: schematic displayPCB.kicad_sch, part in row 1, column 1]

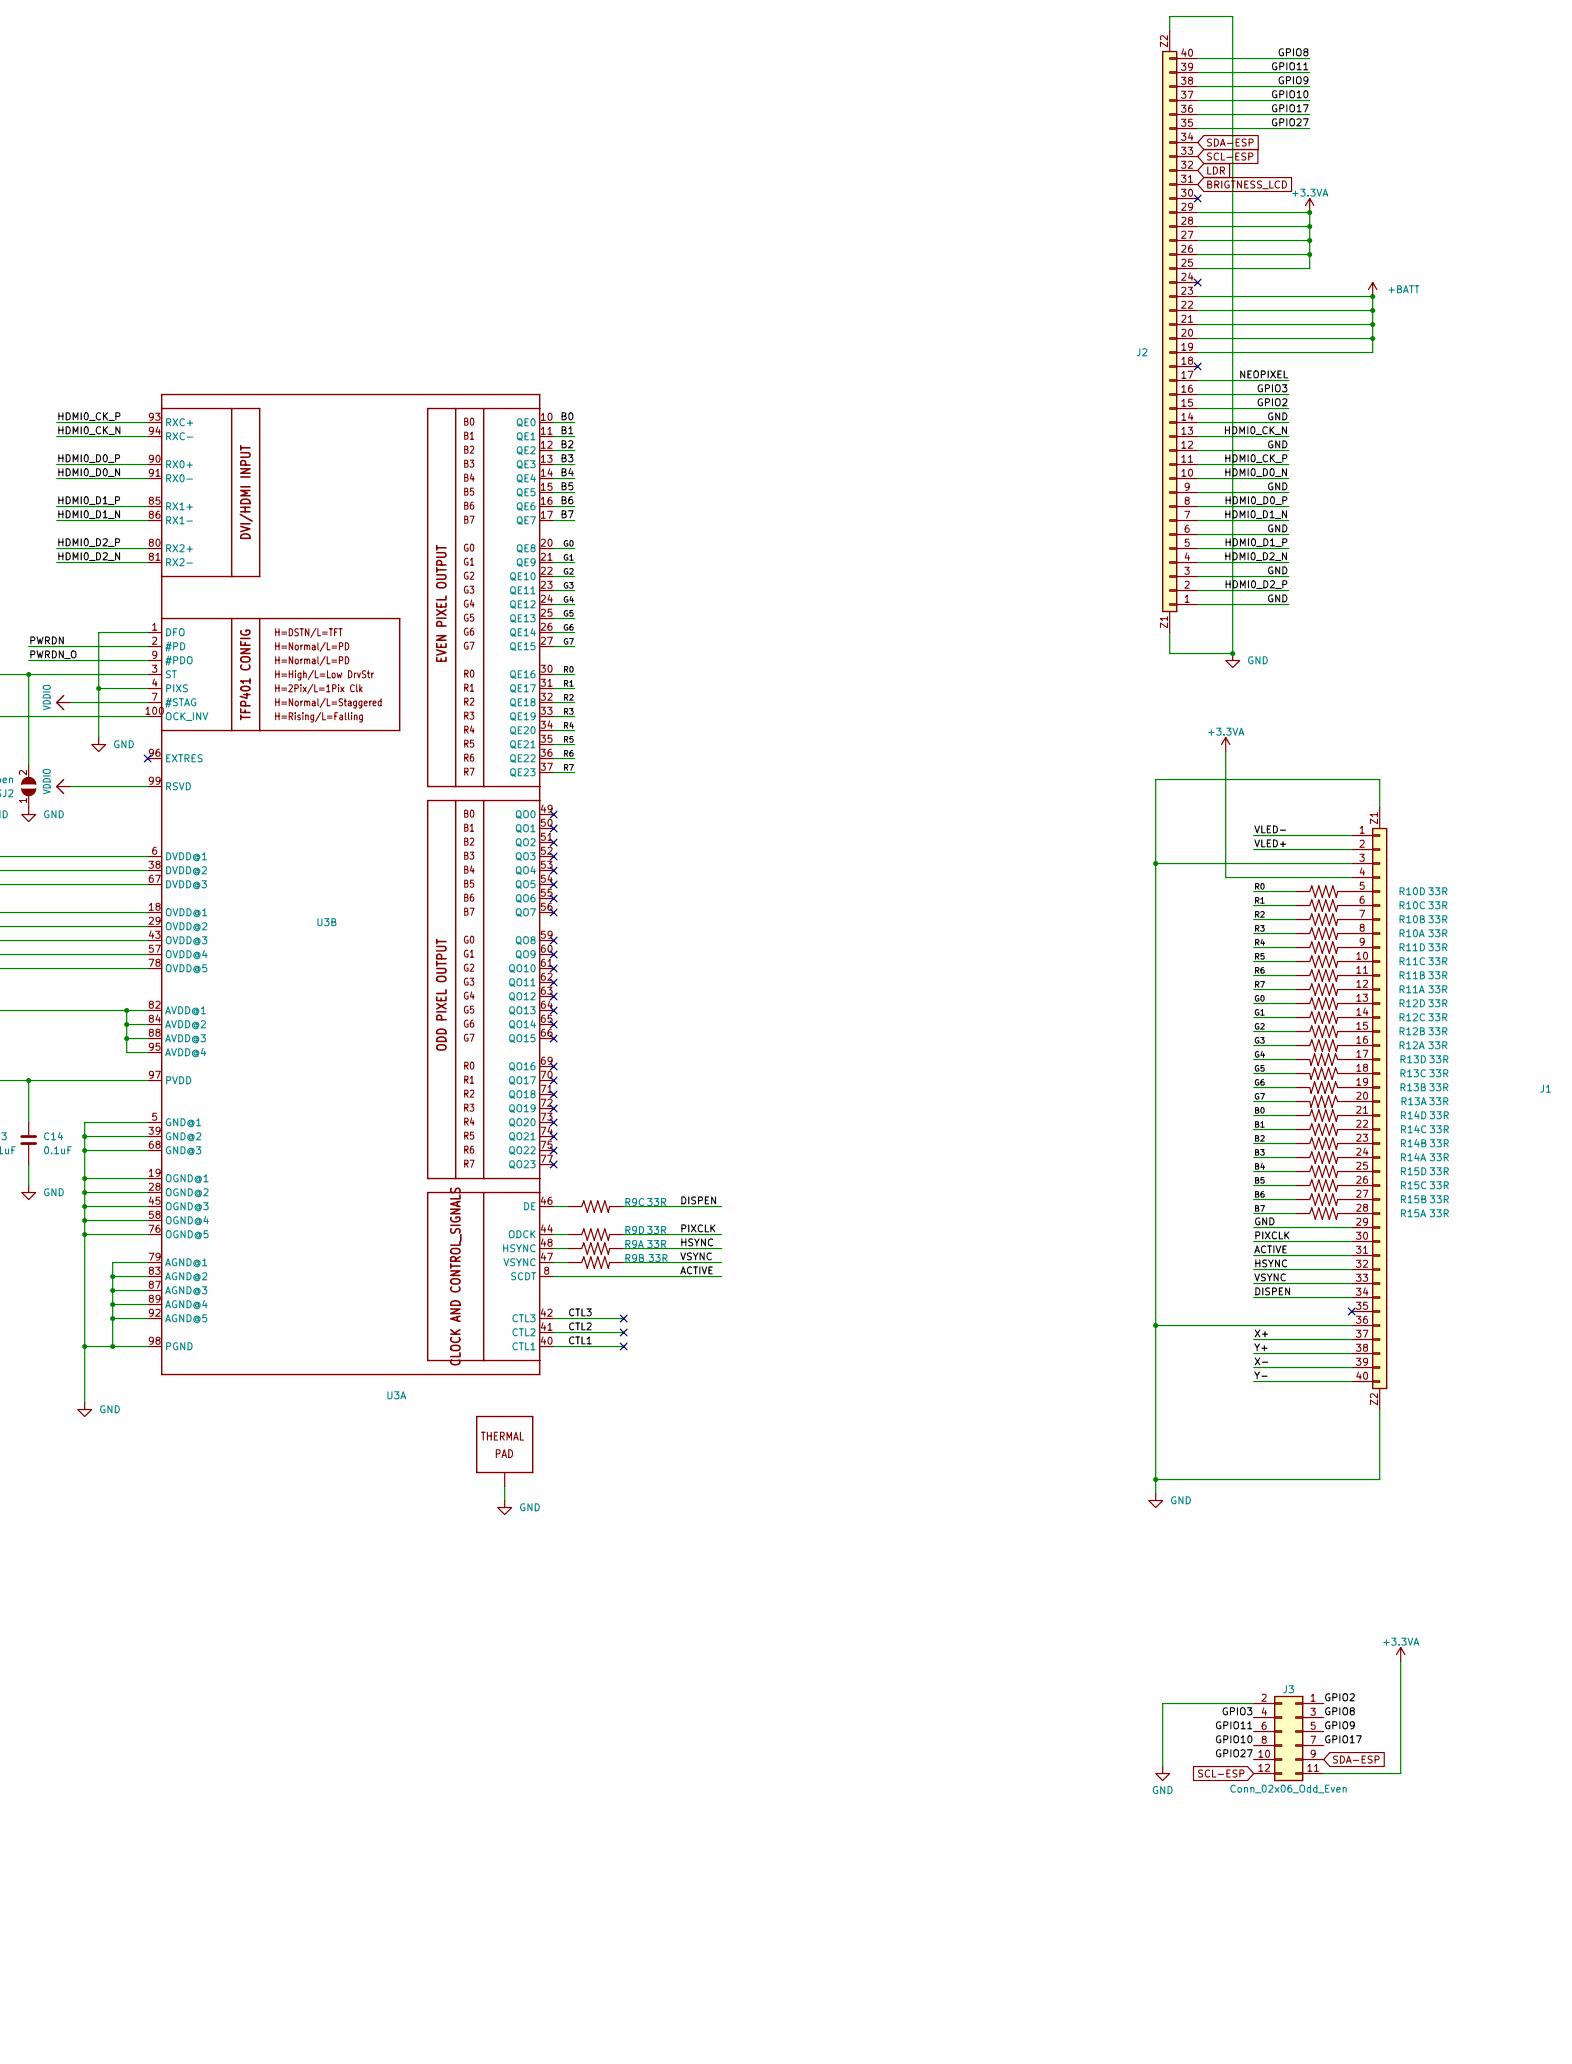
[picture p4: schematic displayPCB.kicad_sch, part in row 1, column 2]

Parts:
C1, C5: 10uF; Capacitor-1206
C2, C3: 1uF; Capacitor-0805
C4, C6, C7, C8, C9, C10, C11, C12, C13, C14: 0.1uF; Capacitor-0805
D1: 2N4148; Diode-SOD-323
FB1, FB2, FB3, FB4: 0R; Ferrite-0805
FID1, FID2: Fiducial; Fiducial_1mm_Mask2mm
H1: MountingHole_Pad; MountingHole_5.3mm_M5
J1, J2: FPC-40; FPC-40-0.5mm-horizontal
J3: Conn_02x06_Odd_Even; PinHeader_2x06_P2.54mm_Vertical
JP1: SJ2; SolderJumper-3_P1.3mm_Bridged12_RoundedPad1.0x1.5mm
JP2: SJ1; SolderJumper-3_P1.3mm_Bridged12_RoundedPad1.0x1.5mm
L1: 22uH; Inductor-4.0x4.0_H3
LDR1: LDR; LDR-5506-D5mm
LED1: WS2812B3535; LED-3535(WS2812B)
P1: Solder_pad; TestPoint-Pad_D1.5mm
R1: 15R; Resistor-0805
R2: 10R; Resistor-0805
R3, R4, R16: 100K; Resistor-0805
R5: 1K; Resistor-0805
R7, R8: 10K; Resistor-0805
R9, R10, R11, R12, R13, R14, R15: 33R; Resistor-4x0603
SJ1, SJ2, SJ3: Solder_jumper-Open; SolderJumper-Open
U1: AP3019AKTR-G1-(SOT23-6); SOT-23-6
U2: TSC2007; TSSOP-16
U3: TFP401-(QFP-100); QFP-100

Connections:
+3.3VA: C4.1, C5.1, FB1.2, FB2.2, FB3.2, FB4.2, J1.4, J2.25, J2.26, J2.27, J2.28, J2.29, J3.11, LDR1.P$1, LED1.3 (VDD), R3.1, R4.1, R16.2, U2.1 (VDD/REF)
+BATT: C1.2, C2.2, J2.19, J2.20, J2.21, J2.22, J2.23, L1.1, U1.6 (VIN)
/ACTIVE: D1.A, J1.31, U3.8 (SCDT)
/B0: R14.4 (1), U3.10 (QE0)
/B1: R14.3 (1), U3.11 (QE1)
/B2: R14.2 (1), U3.12 (QE2)
/B3: R14.1, U3.13 (QE3)
/B4: R15.4 (1), U3.14 (QE4)
/B5: R15.3 (1), U3.15 (QE5)
/B6: R15.2 (1), U3.16 (QE6)
/B7: R15.1, U3.17 (QE7)
/CTL1: U3.40 (CTL1)
/CTL2: U3.41 (CTL2)
/CTL3: U3.42 (CTL3)
/DISPEN: J1.34, R9.6 (2)
/G0: R12.4 (1), U3.20 (QE8)
/G1: R12.3 (1), U3.21 (QE9)
/G2: R12.2 (1), U3.22 (QE10)
/G3: R12.1, U3.23 (QE11)
/G4: R13.5 (2), U3.24 (QE12)
/G5: R13.6 (2), U3.25 (QE13)
/G6: R13.7 (2), U3.26 (QE14)
/G7: R13.8 (2), U3.27 (QE15)
/GPIO2: J2.15, J3.1, JP2.3 (B)
/GPIO3: J2.16, J3.4, JP1.3 (B)
/GPIO8: J2.40, J3.3
/GPIO9: J2.38, J3.5
/GPIO10: J2.37, J3.8
/GPIO11: J2.39, J3.6
/GPIO17: J2.36, J3.7
/GPIO27: J2.35, J3.10
/HDMI0_CK_N: J2.13, U3.94 (RXC-)
/HDMI0_CK_P: J2.11, U3.93 (RXC+)
/HDMI0_D0_N: J2.10, U3.91 (RX0-)
/HDMI0_D0_P: J2.8, U3.90 (RX0+)
/HDMI0_D1_N: J2.7, U3.86 (RX1-)
/HDMI0_D1_P: J2.5, U3.85 (RX1+)
/HDMI0_D2_N: J2.4, U3.81 (RX2-)
/HDMI0_D2_P: J2.2, U3.80 (RX2+)
/HSYNC: J1.32, R9.8 (2)
/NEOPIXEL: J2.17, LED1.2 (DI)
/PIXCLK: J1.30, R9.5 (2)
/PWRDN: U3.2 (#PD)
/PWRDN_O: U3.9 (#PDO)
/R0: R10.4 (1), U3.30 (QE16)
/R1: R10.3 (1), U3.31 (QE17)
/R2: R10.2 (1), U3.32 (QE18)
/R3: R10.1, U3.33 (QE19)
/R4: R11.4 (1), U3.34 (QE20)
/R5: R11.3 (1), U3.35 (QE21)
/R6: R11.2 (1), U3.36 (QE22)
/R7: R11.1, U3.37 (QE23)
/SW: L1.2, U1.1 (SW)
/TSC_SCL: JP1.2 (C), R4.2, U2.12 (SCL)
/TSC_SDA: JP2.2 (C), R3.2, U2.11 (SDA)
/VLED+: C3.2, J1.2, U1.5 (VOUT)
/VLED-: J1.1, R1.1, R2.1, U1.3 (FB)
/VSYNC: J1.33, R9.7 (2)
/X+: J1.37, U2.2 (X+)
/X-: J1.39, U2.4 (X-)
/Y+: J1.38, U2.3 (Y+)
/Y-: J1.40, U2.5 (Y-)
AVDD: C12.1, C13.1, FB3.1, U3.82 (AVDD@1), U3.84 (AVDD@2), U3.88 (AVDD@3), U3.95 (AVDD@4)
BRIGTNESS_LCD: D1.C, J2.31, R16.1, U1.4 (CTRL)
GND: C1.1, C2.1, C3.1, C4.2, C5.2, C6.2, C7.2, C8.2, C9.2, C10.2, C11.2, C12.2, C13.2, C14.2, J1.3, J1.29, J1.36, J1.Z1, J1.Z2, J2.1, J2.3, J2.6, J2.9, J2.12, J2.14, J2.Z1, J2.Z2, J3.2, LED1.1 (GND), R2.2, R5.2, R8.1, SJ2.1, SJ3.1, U1.2 (GND), U2.6 (GND), U3.1 (DFO), U3.4 (PIXS), U3.5 (GND@1), U3.19 (OGND@1), U3.28 (OGND@2), U3.39 (GND@2), U3.45 (OGND@3), U3.58 (OGND@4), U3.68 (GND@3), U3.76 (OGND@5), U3.79 (AGND@1), U3.83 (AGND@2), U3.87 (AGND@3), U3.89 (AGND@4), U3.92 (AGND@5), U3.98 (PGND), U3.P$1 (TP), U3.P$2 (TP), U3.P$3 (TP), U3.P$4 (TP), U3.P$5 (TP), U3.P$6 (TP), U3.P$7 (TP), U3.P$8 (TP), U3.P$9 (TP), U3.P$10 (TP), U3.P$11 (TP), U3.P$12 (TP), U3.P$13 (TP), U3.P$14 (TP), U3.P$15 (TP), U3.P$16 (TP), U3.T (TP)
LDR: J2.32, LDR1.P$2, R5.1
unnamed: J1.5, R10.5 (2)
unnamed: J1.6, R10.6 (2)
unnamed: J1.7, R10.7 (2)
unnamed: J1.8, R10.8 (2)
unnamed: J1.9, R11.5 (2)
unnamed: J1.10, R11.6 (2)
unnamed: J1.11, R11.7 (2)
unnamed: J1.12, R11.8 (2)
unnamed: J1.13, R12.5 (2)
unnamed: J1.14, R12.6 (2)
unnamed: J1.15, R12.7 (2)
unnamed: J1.16, R12.8 (2)
unnamed: J1.17, R13.4 (1)
unnamed: J1.18, R13.3 (1)
unnamed: J1.19, R13.2 (1)
unnamed: J1.20, R13.1
unnamed: J1.21, R14.5 (2)
unnamed: J1.22, R14.6 (2)
unnamed: J1.23, R14.7 (2)
unnamed: J1.24, R14.8 (2)
unnamed: J1.25, R15.5 (2)
unnamed: J1.26, R15.6 (2)
unnamed: J1.27, R15.7 (2)
unnamed: J1.28, R15.8 (2)
unnamed: P1.1, U2.10 (*PENIRQ)
unnamed: R1.2, SJ3.2
unnamed: R9.2 (1), U3.47 (VSYNC)
unnamed: R9.3 (1), U3.46 (DE)
unnamed: R9.4 (1), U3.44 (ODCK)
unnamed: R9.1, U3.48 (HSYNC)
unnamed: R8.2, SJ1.2, U3.100 (OCK_INV)
unnamed: C8.1, C9.1, C10.1, C11.1, FB2.1, U3.18 (OVDD@1), U3.29 (OVDD@2), U3.43 (OVDD@3), U3.57 (OVDD@4), U3.78 (OVDD@5)
unnamed: C14.1, FB4.1, U3.97 (PVDD)
unnamed: R7.2, SJ2.2, U3.3 (ST)
SCL-ESP: J2.33, J3.12, JP1.1 (A)
SDA-ESP: J2.34, J3.9, JP2.1 (A)
VDDIO: C6.1, C7.1, FB1.1, R7.1, SJ1.1, U3.6 (DVDD@1), U3.7 (#STAG), U3.38 (DVDD@2), U3.67 (DVDD@3), U3.99 (RSVD)

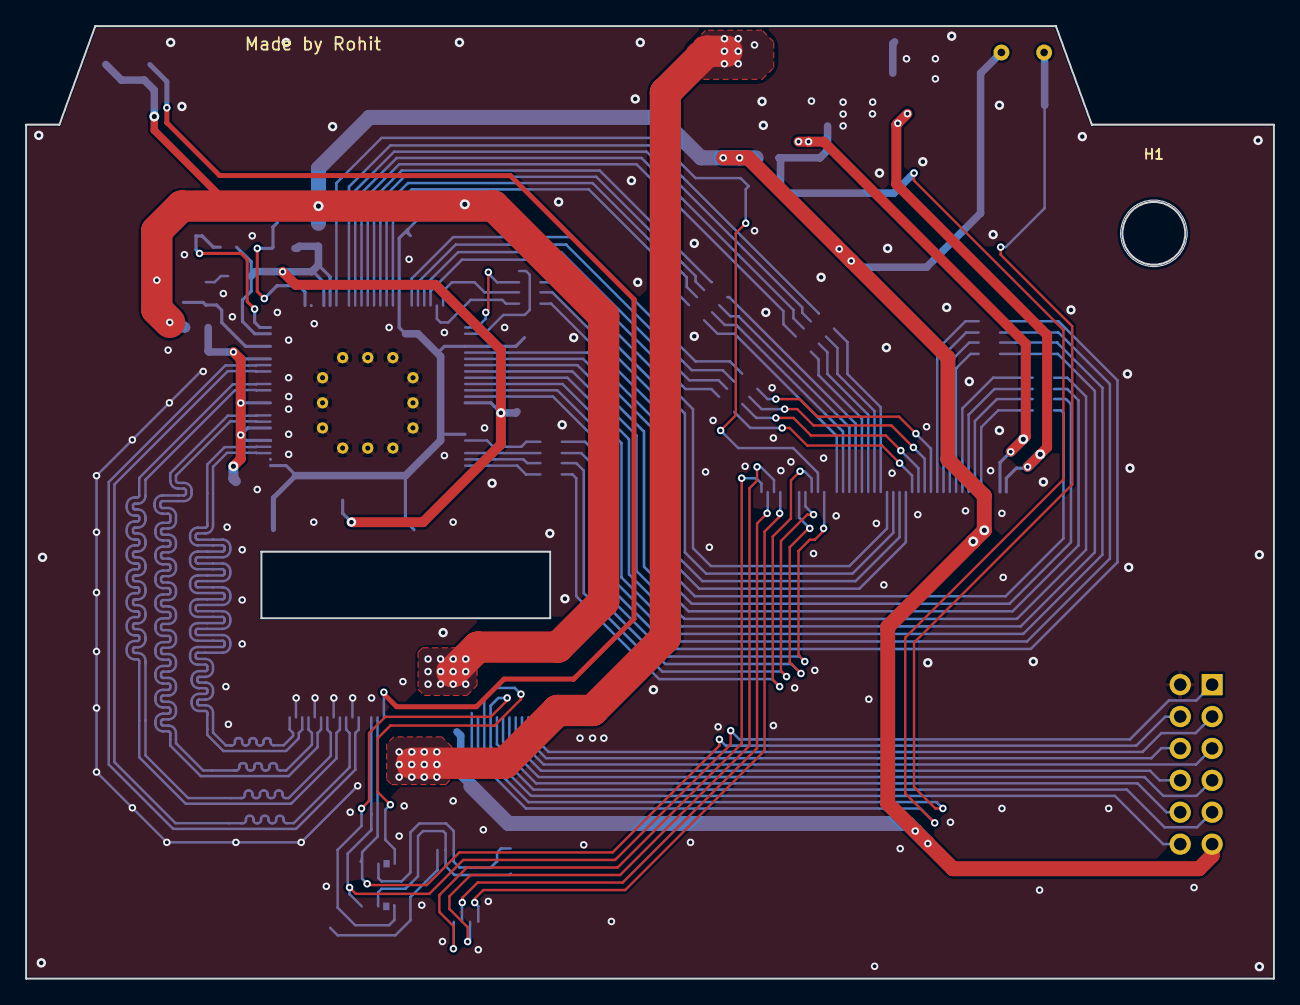
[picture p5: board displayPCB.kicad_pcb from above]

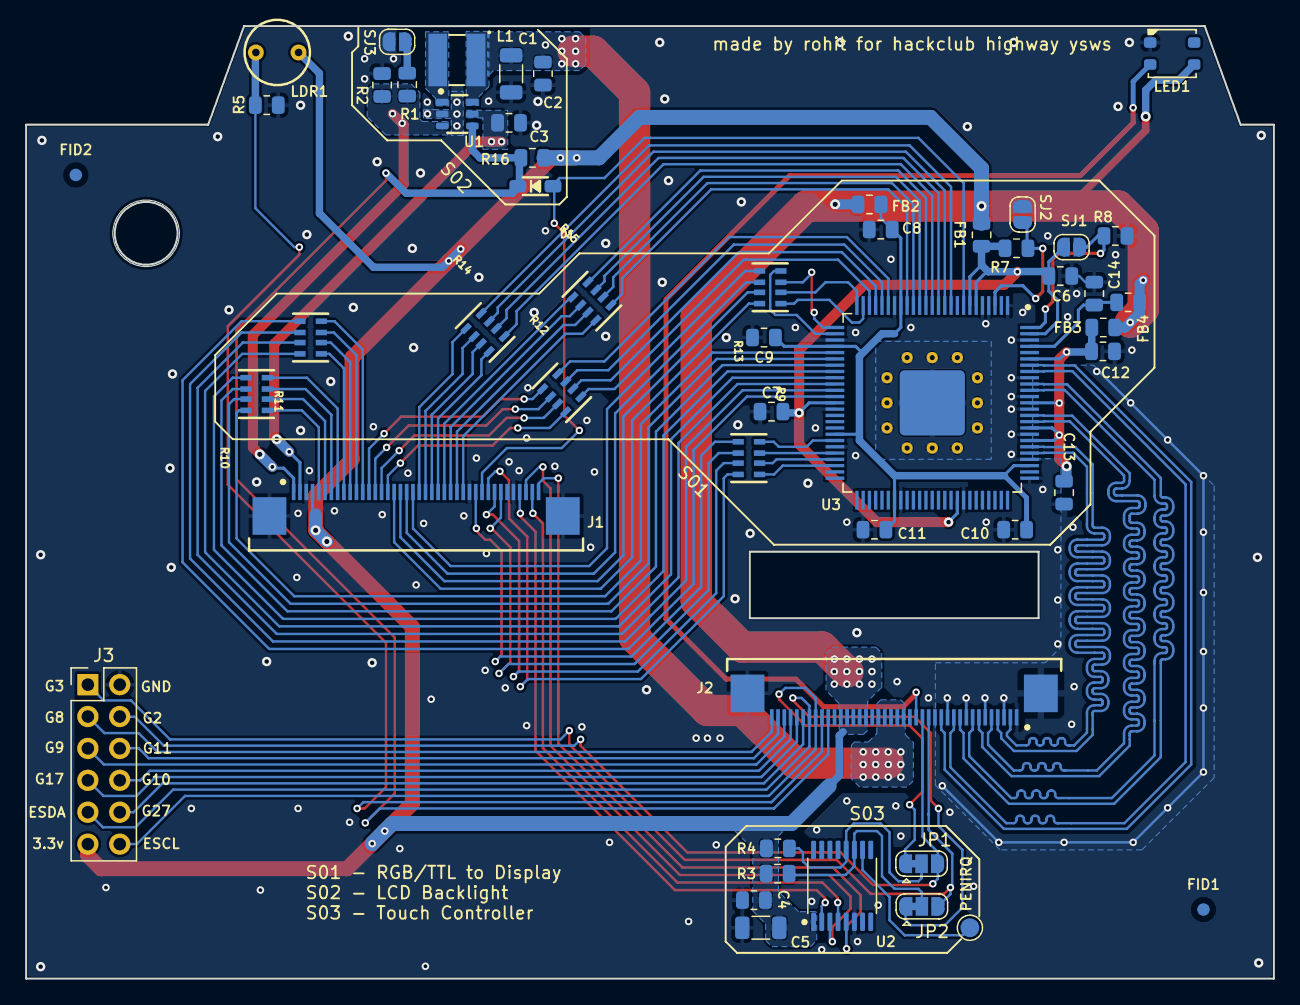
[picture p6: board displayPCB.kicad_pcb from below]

Board: 2 copper layers, 99.4 x 75.8 mm, 52 parts (51 on the bottom side), 98 nets.

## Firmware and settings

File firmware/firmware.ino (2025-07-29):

#include "Arduino.h"
#include <Keypad.h>
#include "USB.h"
#include "USBHIDMouse.h"
#include "USBHIDKeyboard.h"
#include <Wire.h>
#include <SparkFun_MAX1704x_Fuel_Gauge_Arduino_Library.h>  


const char* FIRMWARE_VERSION = "1.0.0";


#define HA 8
#define VA 10
#define MOUSE_MID_BUTTON 9
#define LDR 14
#define LCD_BACKLIGHT 13
#define POWER_BUTTON 12
#define POWER_MAIN 11

// System feature
bool POWER_BUTTON_TO_POWER_OFF = true;
bool USB_DISCONNECT_TO_POWER_OFF = true; 
bool BATTERY_MONITOR_FUNCTION = false; 
bool LDR_MONITOR = false; 

// Define variables for I2C battery monitor
SFE_MAX1704X lipo(MAX1704X_MAX17049);  
double voltage = 0;                    
double batteryPercentage = 0;          
bool alert;                            
bool batteryMonitorDetected = false;  
bool LCD_ON = true;
static uint16_t powered_on = 1000;

// Define variables for USB disconnect detection
const unsigned long USB_DISCONNECT_TIMEOUT = 20000;
unsigned long usbDisconnectStartTime = 0;
bool waitingForReconnect = false;
bool pcIsOn = false;

// Define variables for Power button hold detection
const unsigned long POWER_BUTTON_HOLD_TIME = 5000;
unsigned long lastPowerButtonPressTime = 0;
bool lastPowerButtonState = HIGH; 

// For Mouse
USBHIDMouse mMouse;
int vertZero, horzZero;      
const int mouse_sensitivity = 300;  
bool pan = false;

// For Keypad
USBHIDKeyboard mKeyboard;
const byte KBD_ROWS = 5;
const byte KBD_COLS = 12;
static bool keymapState = 0;

// Keypad event codes:
#define LSW 0x95 // keyboard layout switch
#define SL1 0x97 // Sholder key leftside
#define SL2 0x99 // Sholder key leftside
#define SL3 0x94 // Sholder key leftside
#define SL4 0x96 // Sholder key leftside
//#define LCD_TOGG 0x93


static void lcd_backlight_toggle(void) {
  if (LCD_ON) {
    digitalWrite(LCD_BACKLIGHT, LOW);
    LCD_ON = false;
  } else {
    digitalWrite(LCD_BACKLIGHT, HIGH);
    LCD_ON = true;
  }

  Serial.print("lcd_backlight_toggle: ");
  Serial.println(LCD_ON);
}


static uint8_t keymapAlpha[] = {
  0x00, 0x1E, 0x1F, 0x20, 0x21, 0x22, 0x23, 0x24, 0x25, 0x26, 0x27, 0x00,
//      1     2     3     4     5     6     7     8     9     0
  0x2B, 0x14, 0x1A, 0x08, 0x15, 0x17, 0x1C, 0x18, 0x0C, 0x12, 0x13, SL1,
//Tab,  Q     W     E     R     T     Y     U     I     O     P     SL1
  0x39, 0x04, 0x16, 0x07, 0x09, 0x0A, 0x0B, 0x0D, 0x0E, 0x0F, 0x2A, SL4,
//CL    A     S     D     F     G     H     J     K     L     Bspce SL4
  0xE1, 0x1D, 0x1B, 0x06, 0x19, 0x05, 0x11, 0x10, 0x36, 0x37, 0x28, SL2,
//LSh   Z     X     C     V     B     N     M     ,     .     Enter SL2
  0xE0, 0xE2, 0x52, 0x51, 0x50, 0x4F, 0x2C, 0x00, 0x29, 0xE0, LSW,  SL3
//LCtl  LAlt  AUp   ADn   AL    AR    SPC         ESC   LCtl  LSW   SL3
};

static uint8_t keymapSymbols[] = {
  0x00, 0x3A, 0x3B, 0x3C, 0x3D, 0x3E, 0x3F, 0x40, 0x41, 0x42, 0x43, 0x00,
//      F1    F2    F3    F4    F5    F6    F7    F8    F9    F10
  0x2B, 0x44, 0x45, 0x00, 0x00, 0x00, 0x00, 0x35, 0x2F, 0x30, 0x31, SL1,
//Tab   F11   F12   0     0     0     0     `     [     ]     \     SL1
  0x39, 0x57, 0x56, 0x55, 0x54, 0x67, 0x00, 0x38, 0x33, 0x34, 0x2A, SL4,
//CL    +     -     *     ÷     =     0     /     ;     '     Bspce SL4
  0xE1, 0x00, 0x00, 0x00, 0x00, 0x00, 0x00, 0x00, 0x36, 0x37, 0x28, SL2,
//LSh   0     0     0     0     0     0     0     ,     .     Enter SL2
  0xE0, 0xE2, 0x52, 0x51, 0x50, 0x4F, 0x2C, 0x00, 0x29, 0xE0, LSW,  SL3
//LCtl  LAlt  AUp   ADn   AL    AR    SPC         ESC   LCtl  LSW   SL3
};

static char dummyKeypad[KBD_ROWS][KBD_COLS] = {
  { 0, 1, 2, 3, 4, 5, 6, 7, 8, 9, 10, 11 },
  { 12, 13, 14, 15, 16, 17, 18, 19, 20, 21, 22, 23 },
  { 24, 25, 26, 27, 28, 29, 30, 31, 32, 33, 34, 35 },
  { 36, 37, 38, 39, 40, 41, 42, 43, 44, 45, 46, 47 },
  { 48, 49, 50, 51, 52, 53, 54, 55, 56, 57, 58, 59 }
};

byte kbd_row_pins[KBD_ROWS] = { 37, 35, 41, 40, 38 };                       //connect to the row pinouts of the keypad
byte kbd_col_pins[KBD_COLS] = { 34, 36, 42, 39, 1, 2, 3, 6, 7, 5, 4, 33 };  //connect to the column pinouts of the

//initialize an instance of class NewKeypad
Keypad Keyboard = Keypad(makeKeymap(dummyKeypad), kbd_row_pins, kbd_col_pins, KBD_ROWS, KBD_COLS);

static void switch_Keymap(void) {
  if (keymapState) {
    keymapState = 0;
  } else {
    keymapState = 1;
  }
}

static uint8_t mapKey(char key) {
  if (keymapState)
    return keymapSymbols[key];

  return keymapAlpha[key];
}

static void processKeys(void) {
  if (!Keyboard.getKeys())
    return;
  int i;

  for (i = 0; i < LIST_MAX; i++) {
    if (!Keyboard.key[i].stateChanged) {
      continue;
    }

    uint8_t key = mapKey(Keyboard.key[i].kchar);

    switch (Keyboard.key[i].kstate) {
      case PRESSED:
        {
          Serial.println(key);
          if (key == LSW) {
            //Serial.println("LSW");
            switch_Keymap();
          } else if (key == SL1) {
            //Serial.println("SL1");
            mMouse.click(MOUSE_RIGHT);
          } else if (key == SL2) {
            //Serial.println("SL2");
            mMouse.click(MOUSE_LEFT);
          } else if (key == SL3) {
            //Serial.println(0xE3);
            mKeyboard.pressRaw(uint8_t(0xE3));
          } else if (key == SL4) {
            //Serial.println("SL4");
            scroll = true;
          } else {
            //Serial.println(key);
            mKeyboard.pressRaw(key);
          }
        }
        break;
      case RELEASED:
        {
          if(key == LSW || key == SL1 || key == SL2 || key == SL3 || key == SL4){
            mKeyboard.releaseRaw(uint8_t(0xE3));
            scroll = false;
            pan = false;
          } else {
            mKeyboard.releaseRaw(key);
          }
        }
        break;
    }
  }
}



static void processMouse() {
  // read and scale the two axes:
  int xReading = analogRead(VA) - vertZero;  // read vertical offset
  int yReading = analogRead(HA) - horzZero;  // read horizontal offset

  if (abs(xReading) > 5 || abs(yReading) > 5) {
    if (scroll) {
      delay(500);
      mMouse.move(0, 0, -(xReading / 1000), (yReading / 1000));  //Wheel only supports 0-1 value
    } else {
      mMouse.move((yReading / mouse_sensitivity), (xReading / mouse_sensitivity));
    }
  }

  if (!digitalRead(MOUSE_MID_BUTTON)) {
    mMouse.click(MOUSE_MIDDLE);
    //Serial.println("pressMiddle");
    delay(20);
  }
}

static void power_off(void) {
  
  delay(100);

  
  Serial.println("power_off");
  delay(500);
  digitalWrite(POWER_MAIN, LOW);
}

static void batteryStats() {
  // lipo.getVoltage() returns a voltage value (e.g. 3.93)
  voltage = lipo.getVoltage();
  // lipo.getSOC() returns the estimated state of charge (e.g. 79%)
  batteryPercentage = lipo.getSOC();
  // lipo.getAlert() returns a 0 or 1 (0=alert not triggered)
  alert = lipo.getAlert();

  // Print the variables:
  Serial.print("Voltage: ");
  Serial.print(voltage);  
  Serial.println(" V");

  Serial.print("Percentage: ");
  Serial.print(batteryPercentage);  
  Serial.println(" %");

  Serial.print("Alert: ");
  Serial.println(alert);
  Serial.println();

  delay(500);
}

void setup(void) {
  pinMode(POWER_MAIN, OUTPUT);
  digitalWrite(POWER_MAIN, HIGH);

  pinMode(LDR, INPUT);
  pinMode(VA, INPUT);
  pinMode(HA, INPUT);
  pinMode(MOUSE_MID_BUTTON, INPUT_PULLUP);
  pinMode(POWER_BUTTON, INPUT_PULLUP);
  pinMode(LCD_BACKLIGHT, OUTPUT);

  // Serial setup
  Serial.begin(115200);
  Serial.print("Starting version: ");
  Serial.println(FIRMWARE_VERSION);
  Serial.println();

  //I2C pins
  Wire.begin(18, 17);

  vertZero = analogRead(VA);  
  horzZero = analogRead(HA);  

 
  lcd_backlight_toggle();
  delay(500);
  lcd_backlight_toggle();

 
  Serial.println("Wait for SBC to Finish booting, 30 sec");
  delay(30000);
  Serial.println("end");


  mMouse.begin();
  mKeyboard.begin();
  USB.begin();


  Keyboard.setHoldTime(1);
  Keyboard.setDebounceTime(0);
  delay(500);

  if (BATTERY_MONITOR_FUNCTION) {
   
    if (lipo.begin() == false) {  
      Serial.println(F("MAX17049 not detected"));
      batteryMonitorDetected = false;
    } else {
      Serial.println(F("MAX17049 detected"));
      batteryMonitorDetected = true;

      
      lipo.quickStart();

      
      lipo.setThreshold(20);  
    }
  }
}

void loop(void) {

  /
  if (powered_on > 0) {
    powered_on--;
  } else {
  
    if (POWER_BUTTON_TO_POWER_OFF) {
     
      bool currentPowerButtonState = digitalRead(POWER_BUTTON);

     
      if (currentPowerButtonState == LOW && lastPowerButtonState == HIGH) {
        lastPowerButtonPressTime = millis();
      }

      bool hold = (millis() - lastPowerButtonPressTime) > POWER_BUTTON_HOLD_TIME;

      if (currentPowerButtonState == LOW && hold && digitalRead(POWER_MAIN)) {
        Serial.println("POWER_DOWN - Power button");
        power_off();
      }

  
      lastPowerButtonState = currentPowerButtonState;
    }


    if (USB_DISCONNECT_TO_POWER_OFF) {
    
      pcIsOn = (bool)USB;

      if (!pcIsOn) {
   
        if (!waitingForReconnect) {
          waitingForReconnect = true;
          usbDisconnectStartTime = millis();
          Serial.println("USB disconnect detected - waiting for reconnect");
        }

        else if ((millis() - usbDisconnectStartTime) > USB_DISCONNECT_TIMEOUT) {
          Serial.println("POWER_DOWN - No USB response after timeout");
          power_off();
        }
      } else {

        waitingForReconnect = false;
        usbDisconnectStartTime = 0;  
      }
    }
  }


  processKeys();
  processMouse();

 
  if (BATTERY_MONITOR_FUNCTION && batteryMonitorDetected) { 
    batteryStats(); 
  }


  if(LDR_MONITOR){
    int LDR_m = analogRead(LDR);
    Serial.print("LDR_value: ");
    Serial.println(LDR_m);
  }

  delay(1);  
}
